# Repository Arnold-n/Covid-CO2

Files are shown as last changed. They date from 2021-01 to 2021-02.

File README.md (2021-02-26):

# covid-CO2 CO2 sensor
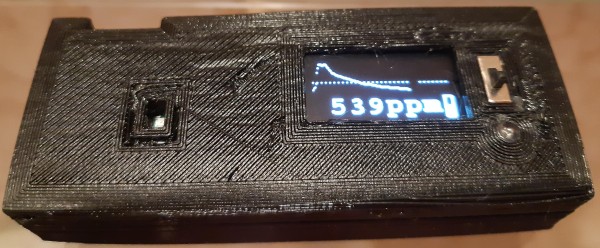
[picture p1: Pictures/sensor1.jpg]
Sensor image with battery

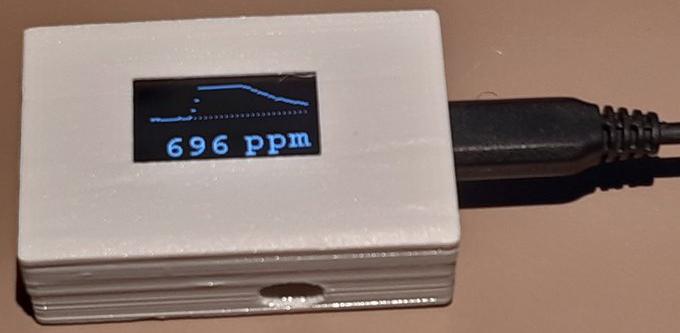
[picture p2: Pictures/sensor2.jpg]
Sensor image without battery


This project explains how to build a small, light and affordable DIY CO2 sensor useful to measure CO2 levels in indoor locations. CO2 can be used as a proxy to estimate the COVID-19 infection risk by aerosols, and thus to control ventilation (opening windows depending on CO2 levels, balancing cold and risk). Being portable it can be used to verify ventilation status in supermarkets or schools.

## Functionality 

The CO2 sensor has:
- an OLED display for CO2 measurement, and a graph for the past hour (default graph range is 400-1000ppm, dashed indicator line at 600ppm)
- optional LED with blinking pattern depending on CO2 level (thresholds at 600, 800, and 1000ppm)
- optional Li-ion battery with on/off switch and battery voltage indicator

It measures ca 20x35x55mm without battery, or ca 20x35x84mm with battery.

It is powered over micro-USB.

## Release history

- 4 January 2021: original release
- 6 January 2021, v1.0.1: bug fix, modified script to ensure LED remains off even if WiFi is not used or absent

## Project overview

There is a detailed illustrated building guide, and pre-built firmware images and 3D print files are provided. The only necessary software effort is to flash an initial Tasmota image to an ESP8266 board. There are different firmware versions depending on the CO2 sensor:
- Winsen MH-Z19B sensor with automatic baseline calibration off (manual calibration needed at least weekly!)
- Winsen MH-Z19B sensor with automatic baseline calibration on
- SenseAir S8 sensor
- Sensirion SCD30 sensor

There are different STL files to print a 3D-case (one bottom and one top file per case) for
- Winsen MH-Z19B version without battery
- Winsen MH-Z19B version with battery
- SenseAir S8 LP version without battery
- SenseAir S8 LP version with battery
- Sensirion SCD30 version without battery (will be uploaded later)
- Sensirion SCD30 version with battery (will be uploaded later)

The STL files can be viewed in a 3D viewer on https://www.thingiverse.com/thing:4712931/files

## Known issues

- For the battery version: the boost circuit does not have over-discharge protection, the design relies on the built-in circuitry of the battery (don't use it without). Some batteries may cycle up and down a few times when empty. When the battery is empty, the boost circuit may use a bit more current than the charge circuit can provide (because of the low battery voltage), so the ESP needs to be powered off until battery has some minimum charge.
- Tasmota script seems to hang approximately once/month (no OLED update, no MQTT update), unclear whether this is caused by sw or hw; sometimes reflashing is needed
- Sometimes the ESP board fails and needs to be replaced, perhaps this is an issue with low-quality boards, couldn't find the cause yet.
- Tasmota devices seem to drop i2c device functionality approximately once/year (OLED dark, MQTT/WiFi/sensor continue to work, i2c devices cannot be found), issue can be resolved by reflashing

## Wish list

- Horizontal display scrolling of graph using SSD1306 scroll command
- Data logging (data is not stored while WiFi is unavailable, for example during store visit)
- LED dimming (for now, can be done via Tasmota console using LedPwmMode \<dimfactor\>)
- OLED dimming to increase OLED lifetime (Tasmota command doesn't work on my OLED)

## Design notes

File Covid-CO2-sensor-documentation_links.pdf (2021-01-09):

Documentation links for Covid-CO2 sensor (https://www.github.com/arnold-n/Covid-CO2)

Item | Link to documentation
Sensirion SCD30 | https://www.sensirion.com/en/download-center/carbon-dioxide-sensors-co2/co2-sensor/
SenseAir S8 LP 004-0-0053 | https://senseair.com/products/size-counts/s8-lp/
Winsen MH-Z19B, 0-2000ppm | https://www.winsen-sensor.com/sensors/co2-sensor/mh-z19b.html
SSD1306 0.96” white OLED I2C (and not the very similar SSD1316) | (not sure whether these are valid for all OLED versions using SSD1306): https://www.crystalfontz.com/controllers/SolomonSystech/SSD1306/339/ (https://www.crystalfontz.com/controllers/SolomonSystech/SSD1306/339/) https://www.vishay.com/docs/37902/oled128o064dbpp3n00000.pdf (https://www.vishay.com/docs/37902/oled128o064dbpp3n00000.pdf)
NodeMCU ESP8266 board | Schematic, dimensional drawing and pinout under Documents via https://robotdyn.com/wifi-nodem-esp8266-32m-flash-ch340g.html (https://robotdyn.com/wifi-nodem-esp8266-32m-flash-ch340g.html)
ESP8266 | https://www.espressif.com/en/support/documents/technical-documents (https://www.espressif.com/en/support/documents/technical-documents)
Tasmota | https://tasmota.github.io/docs/
TC4056 | https://www.analog.com/media/en/technical-documentation/data-sheets/405642f.pdf (https://www.analog.com/media/en/technical-documentation/data-sheets/405642f.pdf)
MT3608 | https://datasheetspdf.com/pdf/909246/AEROSEMI/MT3608/1 (https://datasheetspdf.com/pdf/909246/AEROSEMI/MT3608/1)

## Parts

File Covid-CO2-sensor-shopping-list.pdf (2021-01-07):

Shopping list for Covid-CO2 sensor (https://www.github.com/arnold-n/Covid-CO2)

Item | Example link
Soldering skills | https://www.youtube.com/watch?v=Qps9woUGkvI
Tools, some small wires, pin headers | Generic, and/or https://www.tinytronics.nl/shop/nl/kabels/prototype-draden/breadboard-draden-140-stuks-verschillende-maten-in-doosje (https://www.tinytronics.nl/shop/nl/kabels/prototype-draden/breadboard-draden-140-stuks-verschillende-maten-in-doosje) and https://www.tinytronics.nl/shop/nl/connectoren/pin-header/40-pins-header-male (https://www.tinytronics.nl/shop/nl/connectoren/pin-header/40-pins-header-male)

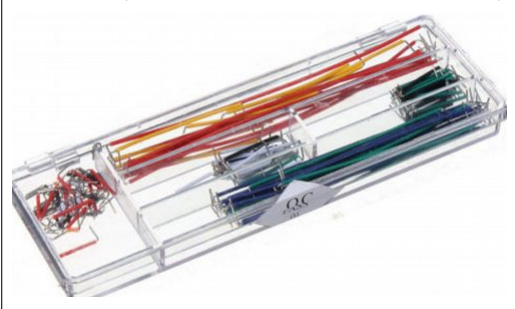
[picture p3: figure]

CO2 sensor: -option 1: Winsen MH-Z19B, 0-2000ppm, but without pre-soldered pins -option 2: SenseAir S8 LP 004-0-0053, but without pre-soldered pins -option 3: Sensirion SCD30 | https://www.tinytronics.nl/shop/nl/sensoren/winsen-mh-z19b-co2-sensor-met-kabel (https://www.tinytronics.nl/shop/nl/sensoren/winsen-mh-z19b-co2-sensor-met-kabel) or https://nl.aliexpress.com/item/32823821163.html (select 2000ppm version) or https://www.digikey.nl/product-detail/en/senseair-north-america-inc/004-0-0053/2194-004-0-0053-ND/10416532 (https://www.digikey.nl/product-detail/en/senseair-north-america-inc/004-0-0053/2194-004-0-0053-ND/10416532) or https://www.antratek.nl/co2-and-rh-t-sensor-scd30 or https://nl.mouser.com/ProductDetail/Sensirion/SCD30
SSD1306 0.96” white OLED I2C (and not the very similar SSD1316) | https://nl.aliexpress.com/item/32804323027.html (used for development) or https://www.tinytronics.nl/shop/nl/display/oled/0.96-inch-oled-display-128*64-pixels-wit-i2c (https://www.tinytronics.nl/shop/nl/display/oled/0.96-inch-oled-display-128*64-pixels-wit-i2c) (looks similar but I2C address mentioned is 0x78?, not sure whether it works)
NodeMCU ESP8266 board (select a reliable seller) | https://robotdyn.com/wifi-nodem-esp8266-32m-flash-ch340g.html (https://robotdyn.com/wifi-nodem-esp8266-32m-flash-ch340g.html) or https://www.tinytronics.nl/shop/nl/communicatie/wi-fi/robotdyn-esp8266-nodemcu (https://www.tinytronics.nl/shop/nl/communicatie/wi-fi/robotdyn-esp8266-nodemcu)
LED/switch PCB | oshpark or any other PCB supplier. In NL, please ask me to avoid shipping costs for these trivial small PCBs.
THT resistors 1k Ohm, 12kOhm, 120kOhm | generic
THT 3mm LED (wires should remain thin near LED) | generic
Switch 1P2T 3.7x8.5mm | https://nl.aliexpress.com/item/1005001659014942.html

| (select 3mm)

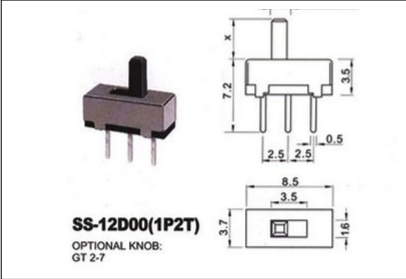
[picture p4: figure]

Li-ion battery 25x30x8mm | https://nl.aliexpress.com/item/32917329258.html
Board with TC4056 charge circuit and MT3608 DC-DC up-converter (note: this board needs a modification because unmodified output is 5.6V or more) | https://nl.aliexpress.com/item/4000711798833.html

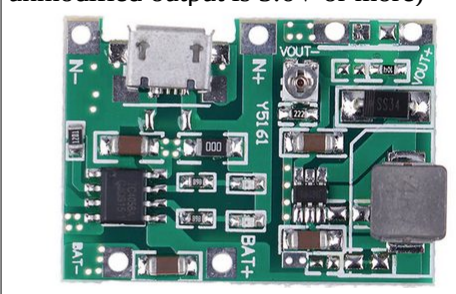
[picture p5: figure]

Software: firmware image with script included | Firmware images in https://github.com/Arnold-n/covid-CO2 Corresponding source code and configuration files: https://github.com/Arnold-n/Tasmota/tree/CO2
Micro-USB cable with power bank and/or power supply | generic

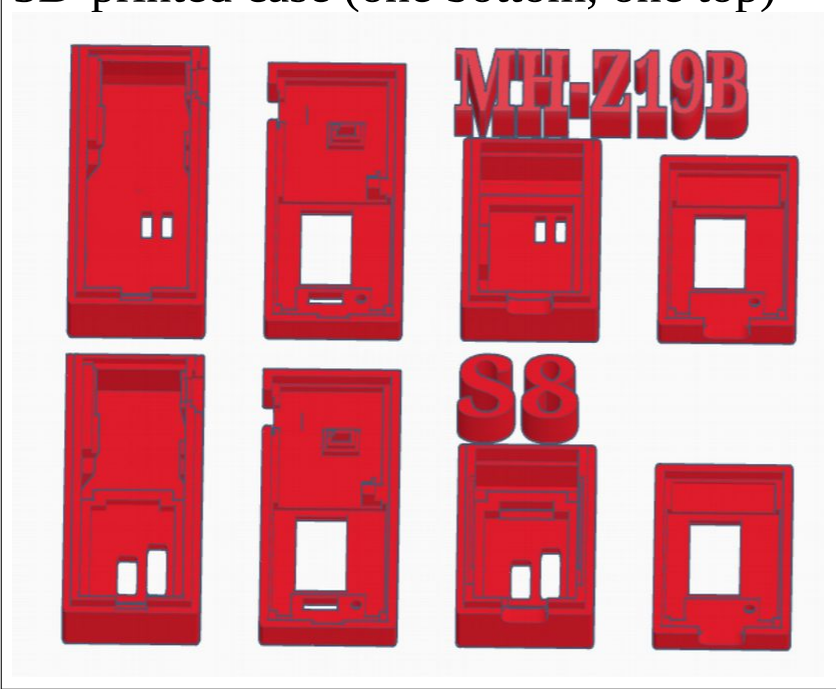
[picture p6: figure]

3D-printed case (one bottom, one top) | STL files at http://www.github.com/arnold-n/Covid-CO2 (http://www.github.com/arnold-n/covid-CO2) and ordering from https://formalize-am.com/en/3d-printing-service/ or https://create3dshop.nl/3dprint/3d-online-printservice/

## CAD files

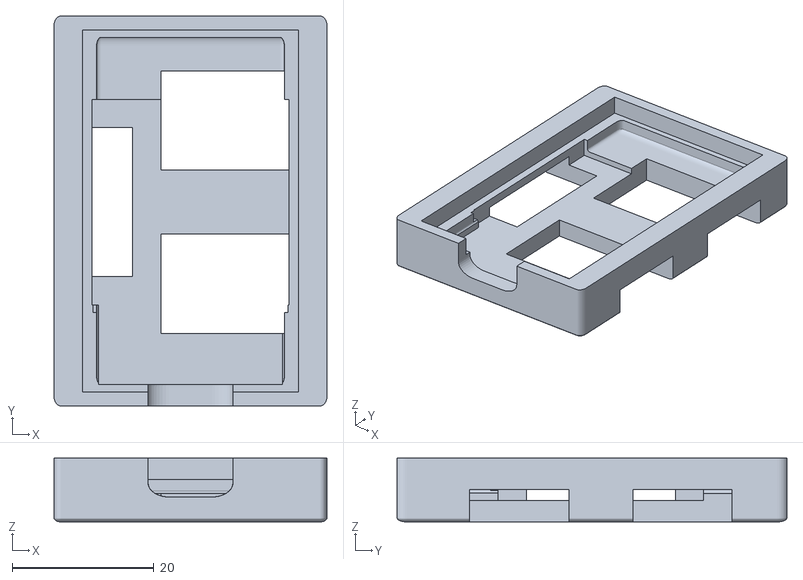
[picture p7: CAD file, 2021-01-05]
3D-case-STL-files/CO2-soldertool-top.stl
38.5 x 55.0 x 9.00

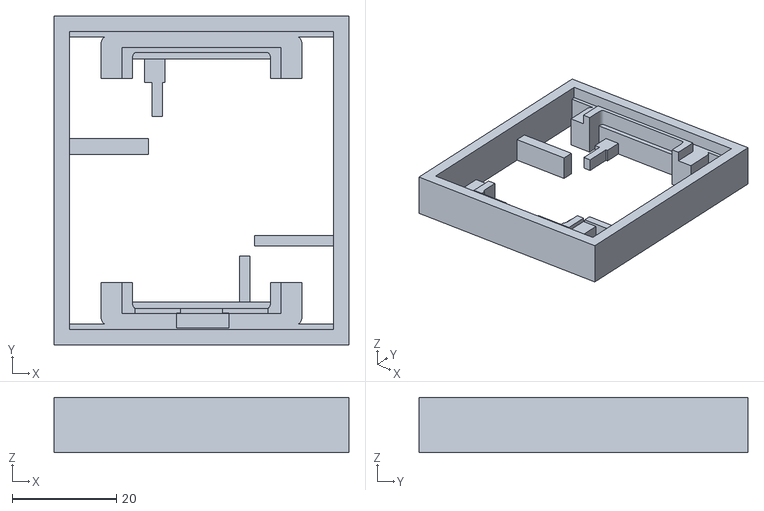
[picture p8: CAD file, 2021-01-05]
3D-case-STL-files/CO2-soldertool-bottom.stl
56.5 x 63.0 x 10.6

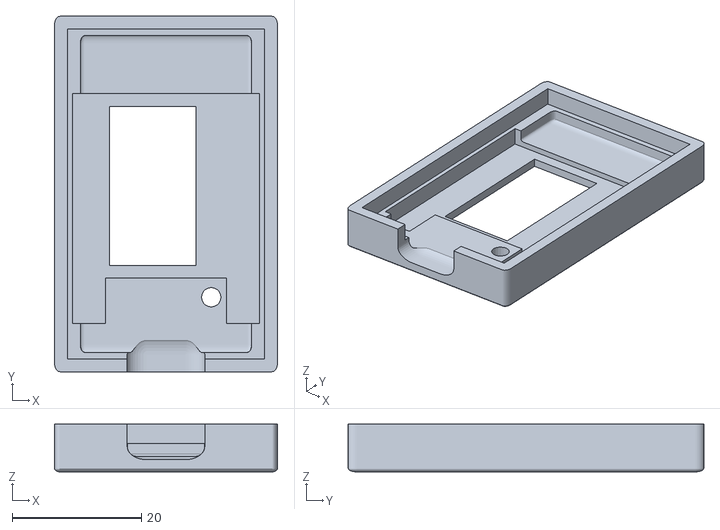
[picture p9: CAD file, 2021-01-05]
3D-case-STL-files/CO2-20210103-top-MHZ.stl
34.5 x 55.0 x 7.40

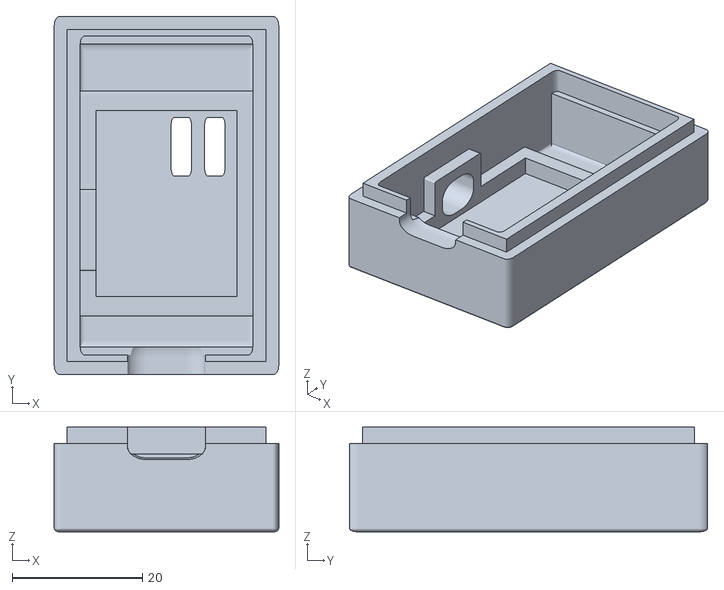
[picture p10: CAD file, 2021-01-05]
3D-case-STL-files/CO2-20210103-bottom-MHZ.stl
34.5 x 55.0 x 16.1

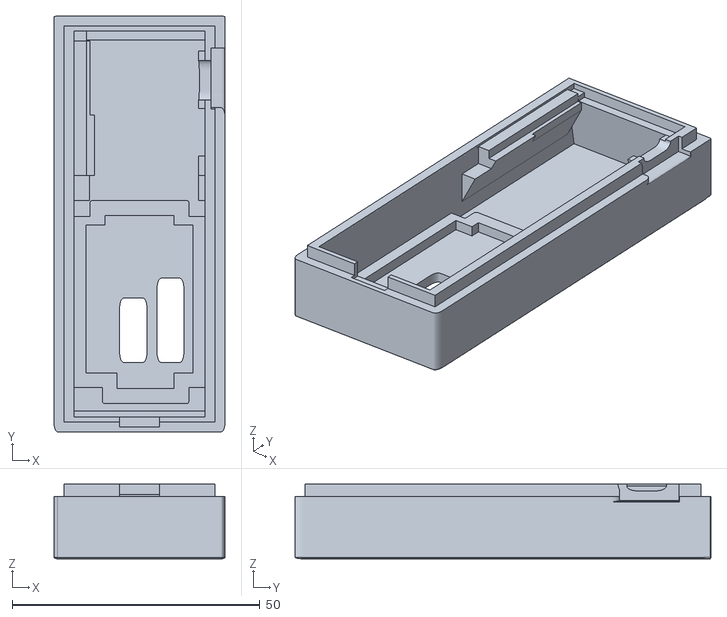
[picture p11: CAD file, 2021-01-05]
3D-case-STL-files/CO2-20210103-bat-bottom-S8.stl
34.5 x 84.0 x 15.1

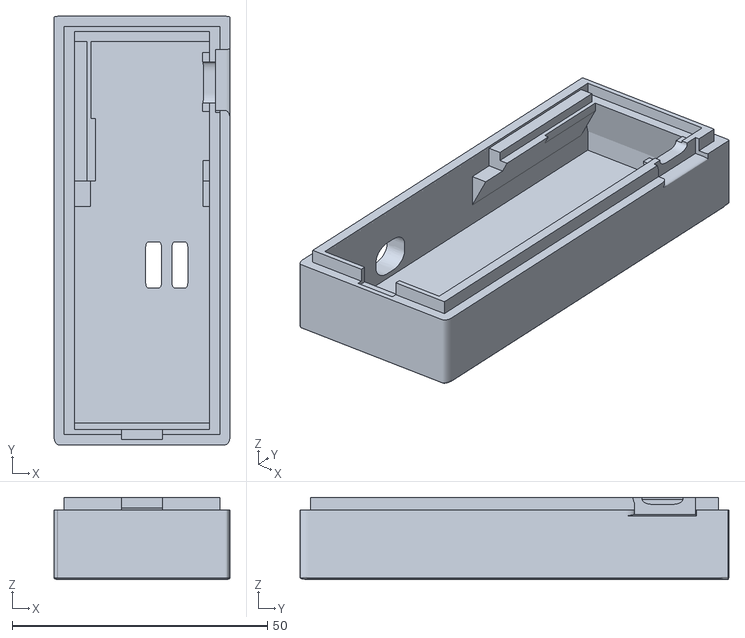
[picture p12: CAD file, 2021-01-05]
3D-case-STL-files/CO2-20210103-bat-bottom-MHZ.stl
34.5 x 84.0 x 16.1

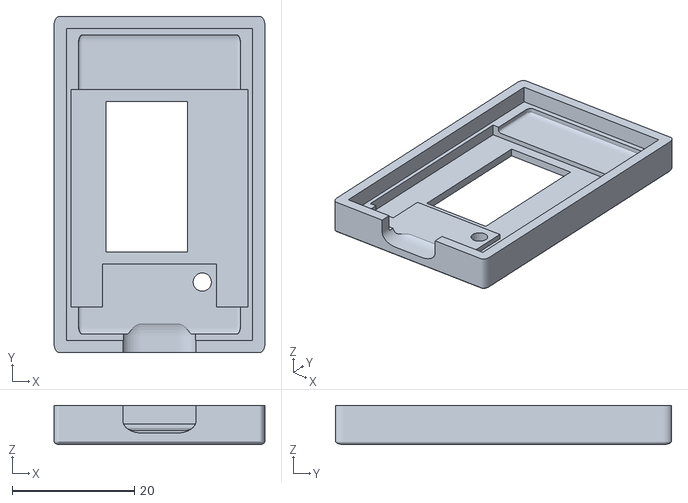
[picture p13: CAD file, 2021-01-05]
3D-case-STL-files/CO2-20210103-top-S8.stl
34.5 x 55.0 x 6.40

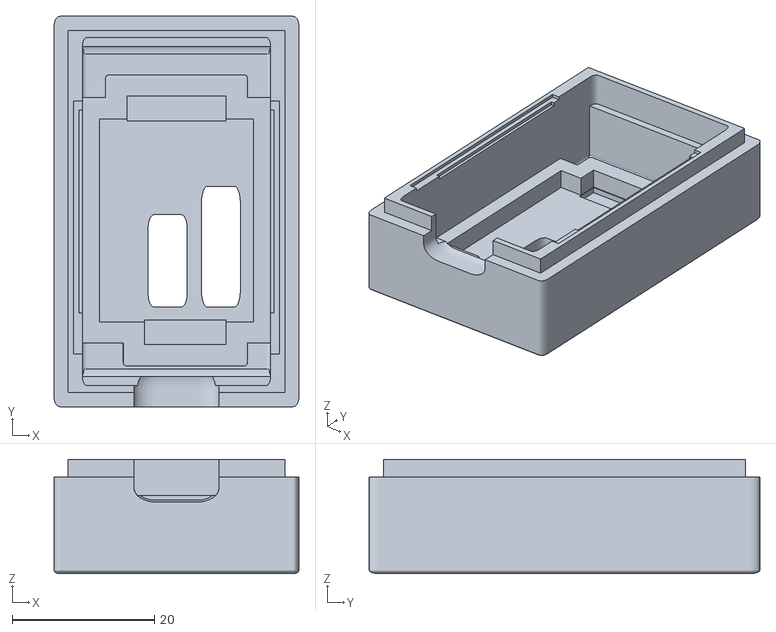
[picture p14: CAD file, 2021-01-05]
3D-case-STL-files/CO2-20210103-bottom-S8.stl
34.5 x 55.0 x 16.1

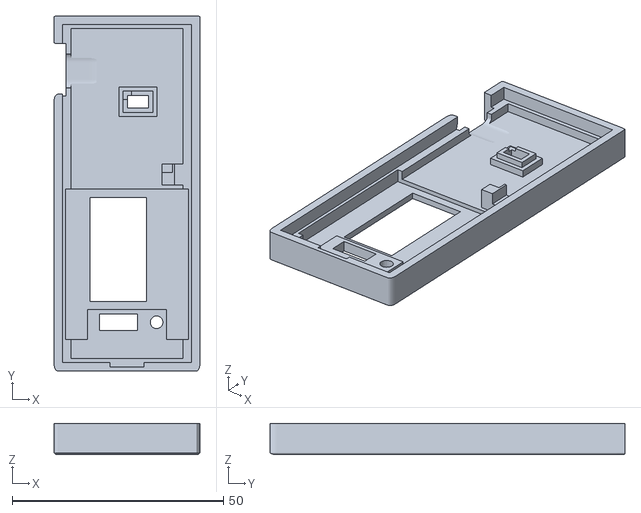
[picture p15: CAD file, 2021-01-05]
3D-case-STL-files/CO2-20210103-bat-top.stl
34.5 x 84.0 x 7.40

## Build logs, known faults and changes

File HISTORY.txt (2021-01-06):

v1.0.0 4 January 2021: initial release
v1.0.1 6 January 2021: added "SetOption31 0" to resolve LED blinking when not connected to WiFi

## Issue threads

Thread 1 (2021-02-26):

Over discharge protection?

SamGurdus1, 2021-02-26:
I just assembled one of these and left it running on battery power overnight. This morning, it seemed to be dead, but after charging it for roughly 20 minutes, it looks like it is mostly charged. So now I'm wondering if the charge & boost circuit has over-discharge protection.

ArnoldNiessen, 2021-02-26:
Thanks for your feedback! The boost circuit does not have over-discharge protection, the design relies on the built-in circuitry of the battery. Some batteries may cycle up and down a few times when empty. When the battery is empty, the boost circuit may use a bit more than the charge circuit, so the ESP needs to be powered off until battery voltage is high enough. I'll add this explanation to the readme.

SamGurdus1, 2021-02-26:
Cool, that makes sense. What kind of battery life are you getting?

ArnoldNiessen, 2021-02-27:
Around 4 hours I guess, did not measure it. Enough for store visits. Deepsleep should lengthen it. At home they are USB-powered (and will cycle in full state, I don't know what this means for battery life time).

Closed 2021-02-27.

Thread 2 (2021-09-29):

Tasmota Configuration

g0lgs, 2021-09-29:
Can you make your user_config_override.h or platformio_override.ini or whatever settings you used to build a version of Tasmota with the required options available ?

Arnold-n, 2021-09-29:
The file user_config_override.h is already present in the CO2 branch of my Tasmota fork. Depending on the sensor, use one of:
[MHZ19B with ABC disabled](https://github.com/Arnold-n/Tasmota/blob/CO2/tasmota/user_config_override_MHZ19B_ABC_disabled.h)
[MHZ19B with ABC enabled](https://github.com/Arnold-n/Tasmota/blob/CO2/tasmota/user_config_override_MHZ19B_ABC_enabled.h)
[S8](https://github.com/Arnold-n/Tasmota/blob/CO2/tasmota/user_config_override_S8.h)
[SCD30](https://github.com/Arnold-n/Tasmota/blob/CO2/tasmota/user_config_override_SCD30.h)
These scripts were written for this CO2 branch and require the options PRECONFIGURED_SCRIPT and MHZ19B_ABC_DISABLE which are part of my CO2 branch but not part of the stable Tasmota branch. The PRECONFIGURED_SCRIPT option is supported by Tasmota's development branch.

The Tasmota development  branch now also includes the pre-compiled script option (PRECONFIGURED_SCRIPT and START_SCRIPT_FROM_BOOT), but does not include the option to disable MHZ19B auto-calibration (MHZ19B_ABC_DISABLE).

I did not use any platformio_override.ini file.

For compilation I used the instructions from [docker-tasmota](https://github.com/tasmota/docker-tasmota).

g0lgs, 2021-09-30:
Thanks for the link.

Closed 2021-09-30.

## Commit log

2021-01-05 Initial release
    [CO2-20210103-bat-bottom-MHZ.stl, CO2-20210103-bat-bottom-S8.stl, CO2-20210103-bat-top-180.stl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]
2021-01-05 Removed duplicate STL file
    [CO2-20210103-bat-top-180.stl]
2021-01-05 Added soldertool STL files
    [CO2-soldertool-bottom.stl, CO2-soldertool-top.stl]
2021-01-06 Added warning that LED blinks when WiFi is not connected
2021-01-06 v1.0.1: resolves LED blinking due to non-connected WiFi
2021-01-06 Added Gerber files
2021-01-06 Added link to thingiverse for 3D-viewing STL files
2021-02-12 mention incidental i2c-loss
2021-02-26 Added remarks on battery protection circuitry and ESP board failures
